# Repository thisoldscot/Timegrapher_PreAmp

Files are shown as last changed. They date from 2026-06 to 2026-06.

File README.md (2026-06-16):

# Timegrapher PreAmp

[][cc-by-nc-sa]

## About the Project

| Timegrapher PreAmp |
| :-----------------------------------------------------------------------------------------------------------: |

Timegrapher PreAmp is the **through-hole** piezo preamplifier board for the
Timegrapher Studio wristwatch timegrapher. It conditions the faint escapement
signal from the piezo pickup and feeds the I²S ADC on the
[carrier HAT](https://github.com/thisoldscot/Timegrapher_Hat). This is the
hand-solderable variant; an SMD version lives in
[Timegrapher_PreAmpSMD](https://github.com/thisoldscot/Timegrapher_PreAmpSMD).
Designed in KiCad. See [DESIGN.md](DESIGN.md) and [BOM.md](BOM.md).

---

## Repository Contents

This repository contains the KiCad design and production files:

- **`TimegrapherPreamp.kicad_pro` / `.kicad_sch` / `.kicad_pcb`** — KiCad project.
- **`Preamp.kicad_sym` / `sym-lib-table`** — schematic symbols.
- **`Production/`** — Gerbers, drill files, and the fabrication zip.
- **`TimegrapherPreamp.step`** — 3D model of the assembled board.
- **`TimegrapherPreamp_sch.pdf`** — schematic PDF.
- **`gen_sch.py` / `gen_pcb.py`** — scripts used to generate the design.
- **`BOM.md`** — bill of materials. **`DESIGN.md`** — design notes.

Refer to the `CHANGELOG.md` for details about updates between versions.

---

## Timegrapher project

Timegrapher Studio is split across several repositories:

| Repository | Contents |
| --- | --- |
| [Timegrapher_OS](https://github.com/thisoldscot/Timegrapher_OS) | Desktop application |
| [Timegrapher_App](https://github.com/thisoldscot/Timegrapher_App) | Mobile companion app |
| [Timegrapher_Firmware](https://github.com/thisoldscot/Timegrapher_Firmware) | ESP32 device firmware |
| [Timegrapher_Hat](https://github.com/thisoldscot/Timegrapher_Hat) | Carrier HAT (PCB) |
| [Timegrapher_PreAmp](https://github.com/thisoldscot/Timegrapher_PreAmp) | Piezo preamp (through-hole) (this repo) |
| [Timegrapher_PreAmpSMD](https://github.com/thisoldscot/Timegrapher_PreAmpSMD) | Piezo preamp (SMD) |
| [Timegrapher_Stand](https://github.com/thisoldscot/Timegrapher_Stand) | 3D-printed stand & fixtures |

---

## Learn More

### Documentation

Build notes, BOM, and assembly guides can be found here:
[ThisOldScot Docs](https://thisoldscot.com)
<!-- TODO: replace with the real docs URL when live -->

### ThisOldScot Community

ThisOldScot Community is a great space for the maker community — get answers to
your questions and solutions for our projects there.
<!-- TODO: add the real community/forum URL -->

### ThisOldScot Discord

Another option to get help and advice from other makers via the ThisOldScot Discord.
<!-- TODO: add the real Discord invite URL -->

---

## Contributing

Contributions are welcome! Here's how you can get involved:

- Submit pull requests to enhance the design or fix issues.
- Report bugs or problems by opening an issue.

We encourage community collaboration to make this project even better.

---

## About ThisOldScot

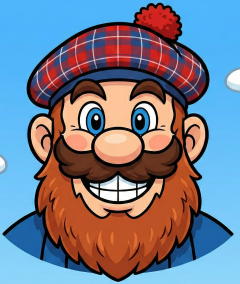
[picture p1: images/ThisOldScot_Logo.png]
ThisOldScot logo


[ThisOldScot](https://thisoldscot.com) enjoys designing and making electronic
products and projects for enthusiasts, from hobbyists to professionals — boards,
sensors, hobby equipment, and anything else that catches my interest. Every
project is designed in-house and built on open-source hardware and software.

---

# Support the team
We :heart: doing research. New hardware (e.g. oscilloscopes, logic analysers,
servos, PCBs) is costly. Feel free to support us and accelerate our research.

Dev | ThisOldScot |
--- | --- |
Buy me a coffee |  |
Ko-fi |  |
<!-- TODO: add the real Buy Me a Coffee / Ko-fi URLs -->

---

## License

This work is licensed under a Creative Commons Attribution-NonCommercial-ShareAlike
4.0 International License. Read more in the LICENSE file located in this repository.

Shield: [][cc-by-nc-sa]

[][cc-by-nc-sa]

[cc-by-nc-sa]: http://creativecommons.org/licenses/by-nc-sa/4.0/
[cc-by-nc-sa-image]: https://licensebuttons.net/l/by-nc-sa/4.0/88x31.png
[cc-by-nc-sa-shield]: https://img.shields.io/badge/License-CC%20BY--NC--SA%204.0-lightgrey.svg

---

**Disclaimer:**

These designs are provided "AS IS", without warranty of any kind, either expressed
or implied. The entire quality and performance of what you do with the contents of
this repository is your responsibility. In no event will ThisOldScot be liable for
any damages or losses arising out of the use or inability to use the contents of
this repository.

> [!WARNING]
> Use responsibly and at your own risk.

---

## Have fun!

Thank you for your support from your fellow makers at ThisOldScot.

Happy Making!

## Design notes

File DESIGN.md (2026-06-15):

# Timegrapher Piezo Pre-Amplifier — DESIGN

Compact **through-hole** piezo pre-amplifier that replaces the bench AD828. It
sits **at the pickup** and drives a single AC audio signal down a short shielded
3-wire lead into the carrier HAT's `J2` "Preamp" header (**+5V / AUDIO_IN / GND**,
see `../carrier/gen_pcb.py`). The carrier already AC-couples and re-biases
`AUDIO_IN` into the PCM1808 (`C_in_l` 1 µF + `R_bl` 22 k → VREF1), so this board's
job is simply: **piezo → bias → amplify → single-ended AC out.**

Built from parts on hand (MCP602-I/P DIP-8, axial 1/4 W metal-film resistors,
1N4148 diodes, disc/film/electrolytic caps). Generated the same way as the
carrier: `gen_sch.py` (kiutils) + `gen_pcb.py` (pcbnew), with `Preamp.kicad_sym`
for the op-amp symbol. **Run the generators with KiCad CLOSED.**

> Replaces the "Piezo preamp board (AD828)" off-board line in `../carrier/BOM.md`.

---

## 1. Why MCP602

The AD828 is a bipolar-input part; its input bias/current noise into the piezo's
high source impedance was a real contributor to the bench noise floor. The
**MCP602** is a CMOS rail-to-rail op-amp (~1 pA input bias current, single 5 V),
which suits the high-Z piezo far better and runs happily on the carrier's 5 V
rail. Both halves of the dual are used (see §3).

## 2. Signal chain

```
 piezo ─┬─ R1 4.7M ─┐            MCP602-A (gain ~10x, HP-shaped)
        ├─ C1 100pF ┤ all to     +IN(3)┌────────┐OUT(1) ── AUDIO_OUT ── J_OUT.2
        ├─ D1 ▷|────┤ VREF        ──────┤        ├──────────────┬──────────────
        └─ D2 |◁────┘ (2.5V)      -IN(2)└────────┘              │
                                   │                            R5 100k (feedback)
                                   └────── R6 10k ── R7 1k ── C4 100nF ── GND
                                          (gain-set leg, AC-grounded via C4)

 VREF buffer (MCP602-B):  +5VF ─ R3 10k ─┬─ R4 10k ─ GND
                                         ├─ C3 10µF ─ GND
                                    VREF_DIV ─ +IN(5) ┌──┐ OUT(7) ─ VREF
                                                 -IN(6)┴──┘   (unity buffer)
 Power:  J_OUT.1 +5V ─ R_FILTER 10Ω ─┬─ +5VF (op-amp VDD pin 8, divider)
                                     ├─ C_FILTER 100µF ─ GND
                                     └─ C_dec 100nF ─ GND
```

## 3. Improvements over the source design doc (approved)

1. **Active virtual ground (uses the 2nd op-amp).** The source design left
   op-amp B (pins 5/6/7) floating — bad practice for CMOS (drift/oscillation) and
   a wasted half. Here **U1-B is a unity-gain buffer** driving the 2.5 V `VREF`
   from the R3/R4 divider. This gives a **low-impedance, quiet bias rail** for the
   high-Z input network and the diode clamps → better hum/PSRR. Same part count.
2. **High-pass corner corrected & tuned.** The doc claimed "7.2 Hz"; with R6+R7
   (11 k) and the original 22 nF the AC-gain corner is actually **~660 Hz**. We
   set **C4 = 100 nF → ~145 Hz**. Below the corner gain is ×1, above it ×~10, so
   the stage gives ~×10 to the tick's transient while leaving 50/60 Hz mains hum
   at unity — i.e. an **~10× tick-to-hum improvement at the output** (the bench
   noise floor was largely mains pickup on the high-Z node). 100 nF (vs 22 nF)
   lowers the corner so more of the tick's body is amplified.
3. **Added VDD decoupling (`C_dec` 100 nF).** The source schematic had none; a
   ceramic right at pin 8 is standard and cheap.
4. **Gain kept tunable.** `R5` (100 k) is the single gain knob. With the new
   pin-coupled flexing pickup the signal is far larger than the loose-disc AD828
   setup, so ×10 is a sane start; raise `R5` (e.g. 220 k → ×21) if ticks are weak.

## 4. Net list (pad → net) — authoritative, mirrors `gen_sch.py`/`gen_pcb.py`

| Ref | Value | Pad → net |
|---|---|---|
| **U1** | MCP602-I/P | 1 `AUDIO_OUT`, 2 `FB`, 3 `PZ`, 4 `GND`, 5 `VREF_DIV`, 6 `VREF`, 7 `VREF`, 8 `+5VF` |
| R_FILTER | 10 Ω | 1 `+5V`, 2 `+5VF` |
| C_FILTER | 100 µF | 1 `+5VF`, 2 `GND` |
| C_dec | 100 nF | 1 `+5VF`, 2 `GND` |
| R3 | 10 k | 1 `+5VF`, 2 `VREF_DIV` |
| R4 | 10 k | 1 `VREF_DIV`, 2 `GND` |
| C3 | 10 µF | 1 `VREF_DIV`, 2 `GND` |
| R1 | 4.7 M | 1 `PZ`, 2 `VREF` |
| C1 | 100 pF | 1 `PZ`, 2 `VREF` |
| D1 | 1N4148 | 1 `PZ`, 2 `VREF` |
| D2 | 1N4148 | 1 `VREF`, 2 `PZ` |
| R5 | 100 k | 1 `AUDIO_OUT`, 2 `FB` |
| R6 | 10 k | 1 `FB`, 2 `GLEG` |
| R7 | 1 k | 1 `GLEG`, 2 `GLEGC` |
| C4 | 100 nF | 1 `GLEGC`, 2 `GND` |
| J_IN | piezo (2-pin) | 1 `PZ`, 2 `VREF` |
| J_OUT | to carrier (3-pin) | 1 `+5V`, 2 `AUDIO_OUT`, 3 `GND` |

`D1`/`D2` are an anti-parallel clamp: they limit the `PZ` node to ≈ ±0.6 V around
`VREF`, protecting the CMOS inputs (and the ADC) from piezo spikes without
clipping normal small ticks.

## 5. Component values & rationale

- **R1 4.7 M** — input bias to `VREF` and, with the piezo's ~15 nF native
  capacitance, sets the **input high-pass ≈ 2 Hz** (keeps the tick's body).
- **C1 100 pF (NP0)** — small RF/EMI shunt across the input. (It does *not* form a
  meaningful LPF against the piezo's much larger capacitance — the source doc's
  rationale was off — but it's a harmless, worthwhile RF bleed.)
- **R3/R4 10 k + C3 10 µF** — 2.5 V divider, buffered by U1-B.
- **R5 100 k / (R6 10 k + R7 1 k)** — non-inverting gain ≈ 1 + 100k/11k ≈ **10.1×**.
- **C4 100 nF** — DC-blocks the gain leg (DC gain = 1, output parks at `VREF`) and
  sets the **~145 Hz** AC-gain corner with R6+R7.
- **R_FILTER 10 Ω + C_FILTER 100 µF** — RC filter (~160 Hz) cleaning the incoming
  5 V; the op-amp draws ~hundreds of µA so the 10 Ω drop is negligible.
- **C_dec 100 nF** — local VDD bypass at pin 8.

## 6. Output coupling

`AUDIO_OUT` is taken **directly** from OUT-A (parked at 2.5 V DC). The carrier's
`C_in_l` (1 µF) blocks that DC and its `R_bl` re-biases into the ADC, so no output
cap is needed for the carrier. The load the op-amp actually sees is a **series**
cap into 22 k (not a shunt cap), so there's no capacitive-load stability concern
and no series isolation resistor is required.

> **Standalone PCM1808-module bench use:** if you drive a bare PCM1808 module
> input that is *not* already AC-coupled, add a 1 µF series cap from `AUDIO_OUT`
> to the module's LIN. Most modules already couple, so usually unnecessary.

## 7. Board / layout plan

- 2-layer, **~32 × 24 mm** target, GND pour both sides + stitching vias (same
  approach as the carrier).
- **U1** central (DIP-8, socket optional/recommended). Axial resistors mounted
  **vertically** (`P2.54mm_Vertical`) to keep the footprint tight.
- **J_IN** (2-pin) on one short edge nearest the piezo; **J_OUT** (3-pin) on the
  opposite edge toward the carrier lead.
- Keep the **`PZ` / +IN node tiny** and surround it with the GND/VREF pour — it's
  the high-impedance antenna node; short traces here matter most for hum.
- Two M2.5 mounting holes.

## 8. Connectors

Default to 0.1″ pin headers (2-pin in, 3-pin out) for easy hand assembly. To mate
the carrier's JST-PH lead directly, swap `J_OUT` to a through-hole JST-PH 3-pin
(`B3B-PH-K-S`) — pinout **1=+5V, 2=AUDIO_IN(=AUDIO_OUT), 3=GND** matches the
carrier's `J2`.

## 9. Bring-up (multimeter, before connecting the ADC)

1. **Supply:** pin 8 → pin 4 reads ~5 V (after the 10 Ω, expect ~4.9–5.0 V).
2. **Bias:** `VREF_DIV` and `VREF` both ≈ 2.5 V; `VREF` (buffered) should track
   the divider closely and stiffly.
3. **Output offset:** OUT-A (pin 1) ≈ 2.5 V at rest. 0 V or 5 V ⇒ a feedback/short
   fault.
4. **Signal:** flick the piezo — scope/`AUDIO_DIAG` should show a large transient.
   With the firmware diagnostic, expect `env/nf` well past threshold on a tick
   once the pickup is pin-coupled.

## 10. Generate

```
# schematic (default Python + kiutils)
python gen_sch.py
# board (KiCad's bundled Python)
"C:/Program Files/KiCad/9.0/bin/python.exe" gen_pcb.py
```

Then open in KiCad (was CLOSED during generation), **Edit → Fill All Zones (B)**,
finish placement/routing, run DRC/ERC, and plot. Do **not** re-annotate in KiCad
(refs are fixed in the generators to keep sch/pcb/BOM in sync) — re-run the
generator instead.

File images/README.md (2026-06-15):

# Images

Place the hero screenshot and brand logo for this repository here.

- `<Repo>.png` — hero image shown at the top of the README.
- `ThisOldScot_Logo.png` — brand logo used in the "About ThisOldScot" section.

> Placeholder — these image files have not been added yet, so the README image
> links will not render until they are supplied.

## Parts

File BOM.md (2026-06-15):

# BOM — Timegrapher Piezo Pre-Amplifier (through-hole, hand-assembled)

Compact 2-layer THT board built from parts on hand. Values follow `DESIGN.md`.
Resistors are 1/4 W metal-film, mounted **vertically** (`P2.54mm_Vertical`) to
save area. No LCSC/PCBA fields — this board is hand-soldered, not fab-assembled.

| Ref | Qty | Value | Footprint | Notes |
|---|---|---|---|---|
| U1 | 1 | **MCP602-I/P** dual CMOS op-amp | `Package_DIP:DIP-8_W7.62mm` | A = gain stage, B = VREF buffer. Use a DIP-8 socket to avoid soldering heat into the part |
| SOCKET1 | 1 | DIP-8 socket (optional) | (same holes as U1) | recommended; not a separate footprint |
| R1 | 1 | 4.7 MΩ 1% | `Resistor_THT:R_Axial_DIN0207_L6.3mm_D2.5mm_P2.54mm_Vertical` | high-Z input bias → VREF; sets ~2 Hz input HP with the piezo cap |
| R3 | 1 | 10 kΩ 1% | `…P2.54mm_Vertical` | VREF divider top |
| R4 | 1 | 10 kΩ 1% | `…P2.54mm_Vertical` | VREF divider bottom |
| R5 | 1 | 100 kΩ 1% | `…P2.54mm_Vertical` | **gain knob** (feedback). 220 k → ×21 if ticks weak |
| R6 | 1 | 10 kΩ 1% | `…P2.54mm_Vertical` | gain-set leg |
| R7 | 1 | 1 kΩ 1% | `…P2.54mm_Vertical` | gain-leg series / HP shaping |
| R_FILTER | 1 | 10 Ω | `…P2.54mm_Vertical` | 5 V RC supply filter |
| D1, D2 | 2 | **1N4148** | `Diode_THT:D_DO-35_SOD27_P7.62mm_Horizontal` | anti-parallel input clamp to VREF |
| C1 | 1 | 100 pF NP0/C0G | `Capacitor_THT:C_Disc_D5.0mm_W2.5mm_P5.00mm` | input RF shunt |
| C4 | 1 | **100 nF** film/X7R | `Capacitor_THT:C_Disc_D5.0mm_W2.5mm_P5.00mm` | gain-leg DC block; ~145 Hz HP corner (was 22 nF/660 Hz in the source doc) |
| C_dec | 1 | 100 nF ceramic | `Capacitor_THT:C_Disc_D5.0mm_W2.5mm_P5.00mm` | VDD decoupling at pin 8 |
| C3 | 1 | 10 µF electrolytic | `Capacitor_THT:CP_Radial_D5.0mm_P2.00mm` | VREF divider decouple |
| C_FILTER | 1 | 100 µF electrolytic | `Capacitor_THT:CP_Radial_D6.3mm_P2.50mm` | 5 V bulk |
| J_IN | 1 | 2-pin header | `Connector_PinHeader_2.54mm:PinHeader_1x02_P2.54mm_Vertical` | piezo: 1=PZ, 2=VREF (shield) |
| J_OUT | 1 | 3-pin header | `Connector_PinHeader_2.54mm:PinHeader_1x03_P2.54mm_Vertical` | to carrier J2: 1=+5V, 2=AUDIO_IN, 3=GND |
| H1, H2 | 2 | M2.5 mounting hole | `MountingHole:MountingHole_2.7mm_M2.5` | no symbol (DRC "extra footprint" expected) |

## Notes
- **C4 changed to 100 nF** (from the source doc's 22 nF) to put the high-pass at
  ~145 Hz — see `DESIGN.md §3`. If you only have 22 nF, the board still works
  (corner ~660 Hz, a touch more low-end roll-off).
- Swap `J_OUT` to a THT **JST-PH 3-pin** (`Connector_JST:JST_PH_B3B-PH-K_1x03_P2.00mm_Vertical`)
  to mate the carrier's JST-PH lead directly.
- Footprint names are stock KiCad 9 libs; if `gen_pcb.py` reports a missing
  footprint, adjust the name to the one present in your install.

## Off-board
| Item | Notes |
|---|---|
| 27 mm piezo disc + centre pin/stud pickup | rim-supported, ceramic-down, brass-up — see chat notes |
| Short shielded 2-conductor lead | piezo → J_IN (signal + shield→VREF) |
| Short shielded 3-conductor lead | J_OUT → carrier J2 (+5V / signal / GND) |

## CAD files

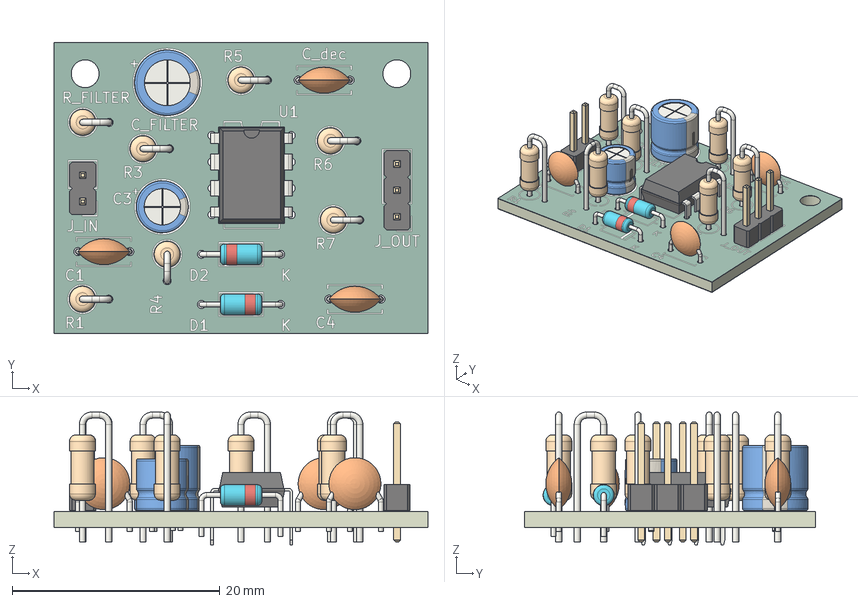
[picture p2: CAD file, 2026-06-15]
TimegrapherPreamp.step
36.0 x 28.0 x 12.8 mm
PinHeader_1x02_P254mm_Vertical
R_Axial_DIN0207_L63mm_D25mm_P254mm_Vertical x 7
C_Disc_D50mm_W25mm_P500mm x 3
D_DO-35_SOD27_P7.62mm_Horizontal x 2
CP_Radial_D63mm_P250mm
PinHeader_1x03_P254mm_Vertical
CP_Radial_D50mm_P200mm
DIP-8_W7.62mm
TimegrapherPreamp_silkscreen x 2
TimegrapherPreamp_soldermask x 2
TimegrapherPreamp_PCB

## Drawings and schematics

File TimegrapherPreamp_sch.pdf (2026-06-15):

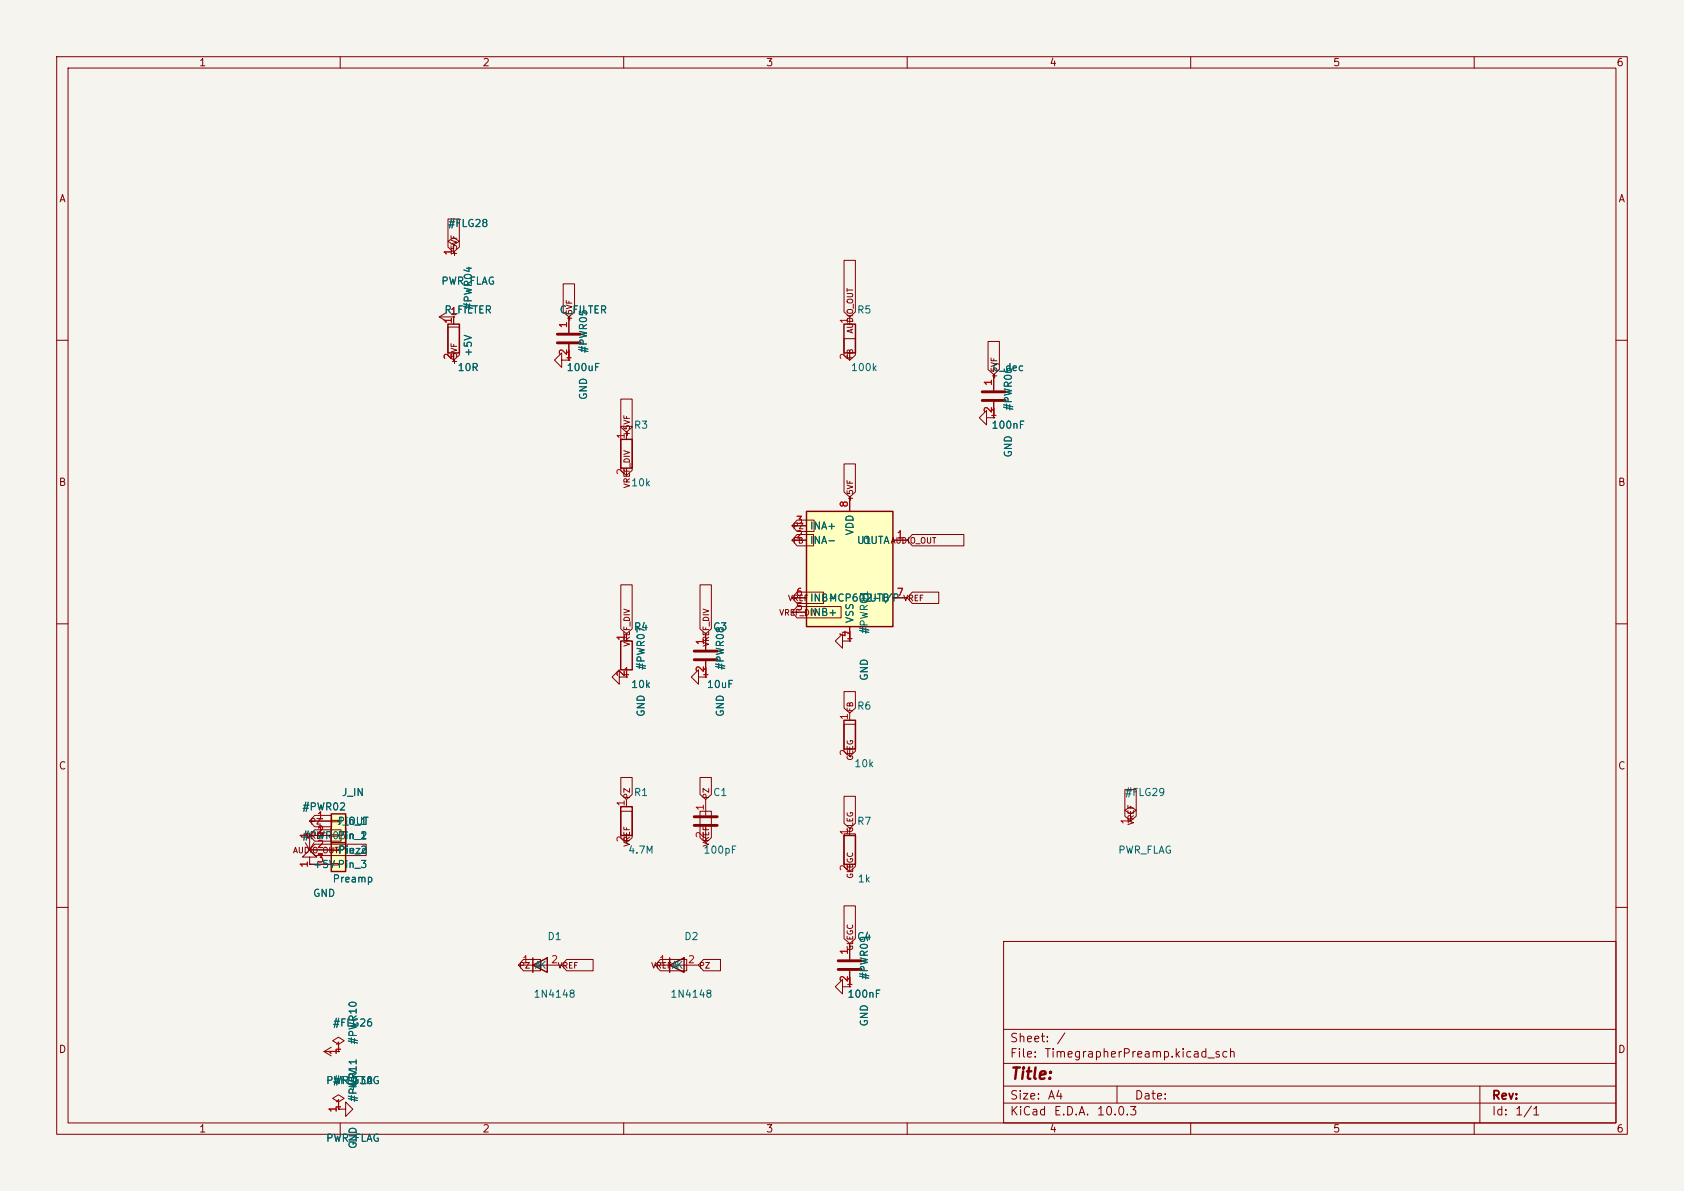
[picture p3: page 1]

Size: A4 | Rev:
KiCad E.D.A. 10.0.3 | Id: 1/1

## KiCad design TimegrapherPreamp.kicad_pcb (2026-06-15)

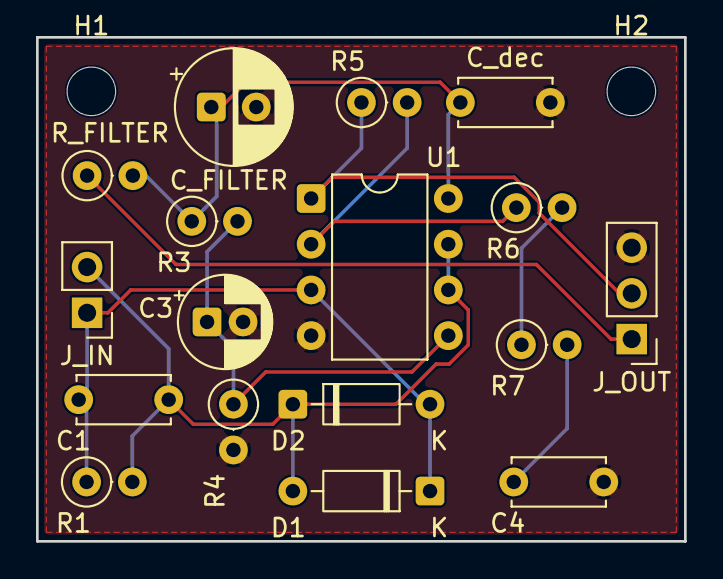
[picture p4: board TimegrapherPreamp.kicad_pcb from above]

Board: 2 copper layers, 36.0 x 28.0 mm, 19 parts (0 on the bottom side), 10 nets.

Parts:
C1: 100pF; C_Disc_D5.0mm_W2.5mm_P5.00mm
C3: 10uF; CP_Radial_D5.0mm_P2.00mm
C4: 100nF; C_Disc_D5.0mm_W2.5mm_P5.00mm
C_FILTER: 100uF; CP_Radial_D6.3mm_P2.50mm
C_dec: 100nF; C_Disc_D5.0mm_W2.5mm_P5.00mm
D1, D2: 1N4148; D_DO-35_SOD27_P7.62mm_Horizontal
H1, H2: M2.5; MountingHole_2.7mm_M2.5
J_IN: Piezo; PinHeader_1x02_P2.54mm_Vertical
J_OUT: Preamp; PinHeader_1x03_P2.54mm_Vertical
R1: 4.7M; R_Axial_DIN0207_L6.3mm_D2.5mm_P2.54mm_Vertical
R3, R4, R6: 10k; R_Axial_DIN0207_L6.3mm_D2.5mm_P2.54mm_Vertical
R5: 100k; R_Axial_DIN0207_L6.3mm_D2.5mm_P2.54mm_Vertical
R7: 1k; R_Axial_DIN0207_L6.3mm_D2.5mm_P2.54mm_Vertical
R_FILTER: 10R; R_Axial_DIN0207_L6.3mm_D2.5mm_P2.54mm_Vertical
U1: MCP602-I/P; DIP-8_W7.62mm

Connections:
+5V: J_OUT.1, R_FILTER.1
+5VF: C_FILTER.1, C_dec.1, R3.1, R_FILTER.2, U1.8
AUDIO_OUT: J_OUT.2, R5.1, U1.1
FB: R5.2, R6.1, U1.2
GLEG: R6.2, R7.1
GLEGC: C4.1, R7.2
GND: C3.2, C4.2, C_FILTER.2, C_dec.2, J_OUT.3, R4.2, U1.4
PZ: C1.1, D1.1, D2.2, J_IN.1, R1.1, U1.3
VREF: C1.2, D1.2, D2.1, J_IN.2, R1.2, U1.6, U1.7
VREF_DIV: C3.1, R3.2, R4.1, U1.5

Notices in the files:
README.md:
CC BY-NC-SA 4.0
